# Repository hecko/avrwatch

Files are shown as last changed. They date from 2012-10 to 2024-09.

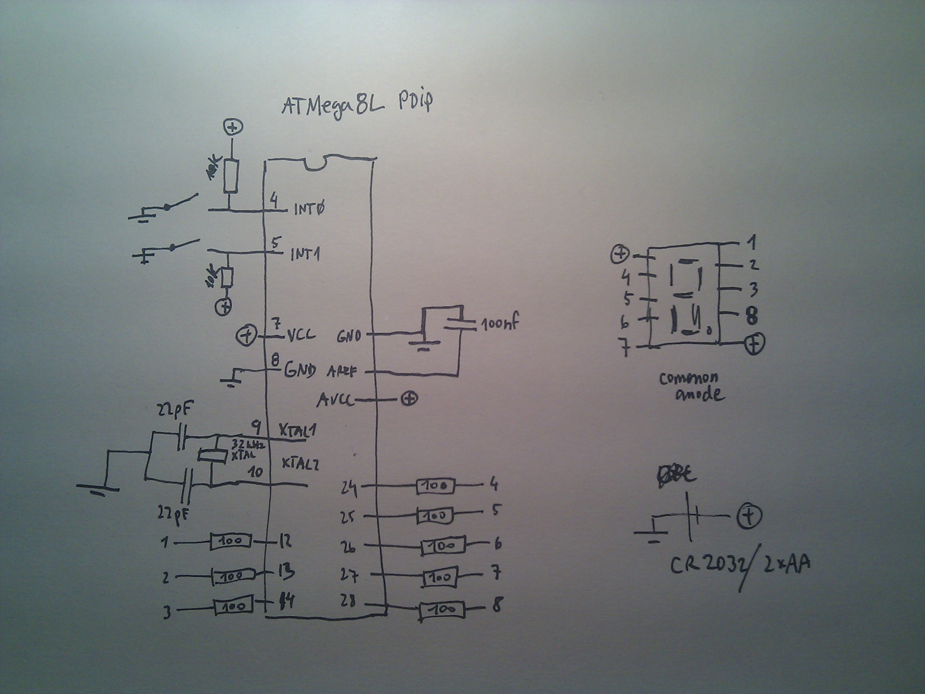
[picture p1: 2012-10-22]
doc/wiring.jpg

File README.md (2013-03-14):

plne funkcna a otestovana na ATMega8L - PDIP verzia

  xtal (32kHz) musi byt zapojeny s externymi kondenzatormi (pozri errata v datasheete atmega8l) - pouzite 22pF (oznacenie 22) (na kazdej nozicke prepojene s GND)
  vsetky GND prepojene
  vsetky VCC prepojene
  AREF prepojeny cez 100n (oznacenie 104) kondenzator na GND
  7 segment display SA36-11GWA cez cca 100 Ohm odpory (spolocna anoda)
  tlacitla su medi INT pinmi a GND s 10K resistormi na pinoch do VCC
  napajane cez CR2032, alebo 2xAA 

wiring

programovanie je testovane na programatore usbtiny

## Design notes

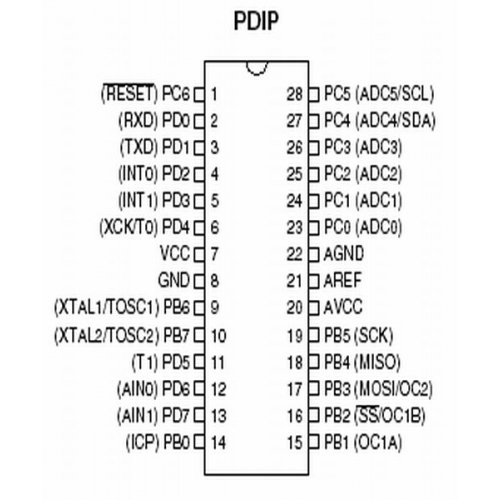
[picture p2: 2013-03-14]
doc/atmega8.jpg

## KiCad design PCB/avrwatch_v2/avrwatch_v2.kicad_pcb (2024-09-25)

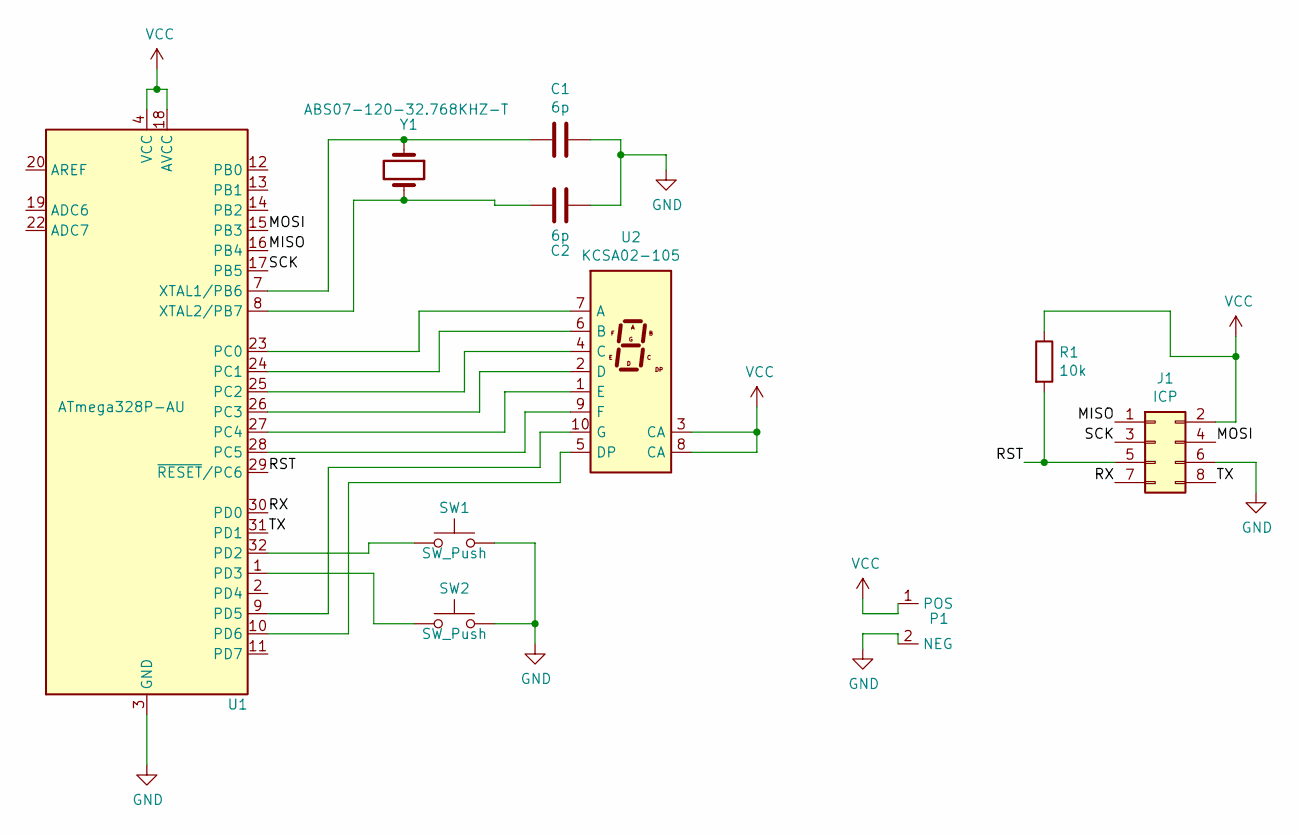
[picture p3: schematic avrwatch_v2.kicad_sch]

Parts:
C1, C2: 6p; C_0603_1608Metric
J1: ICP; PinHeader_2x04_P2.54mm_Vertical
P1: CR2032-120591
R1: 10k; R_0603_1608Metric
SW1, SW2: SW_Push; SW_PUSH_6mm_H9.5mm_center
U1: ATmega328P-AU; TQFP-32_7x7mm_P0.8mm
U2: KCSA02-105; KCSC02-105
Y1: ABS07-120-32.768KHZ-T; Crystal_SMD_3215-2Pin_3.2x1.5mm; FARNELL 2467864

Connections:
/MISO: J1.1, U1.16 (PB4)
/MOSI: J1.4, U1.15 (PB3)
/RST: J1.5, R1.2, U1.29 (~RESET/PC6)
/RX: J1.7, U1.30 (PD0)
/SCK: J1.3, U1.17 (PB5)
/TX: J1.8, U1.31 (PD1)
GND: C1.1, C2.1, J1.6, P1.2 (NEG), SW1.2, SW2.2, U1.3 (GND), U1.5 (GND), U1.21 (GND)
unnamed: U1.23 (PC0), U2.7 (A)
unnamed: U1.24 (PC1), U2.6 (B)
unnamed: U1.25 (PC2), U2.4 (C)
unnamed: U1.26 (PC3), U2.2 (D)
unnamed: U1.27 (PC4), U2.1 (E)
unnamed: U1.28 (PC5), U2.9 (F)
unnamed: SW1.1, U1.32 (PD2)
unnamed: SW2.1, U1.1 (PD3)
unnamed: U1.9 (PD5), U2.10 (G)
unnamed: U1.10 (PD6), U2.5 (DP)
unnamed: C1.2, U1.7 (XTAL1/PB6), Y1.1
unnamed: C2.2, U1.8 (XTAL2/PB7), Y1.2
VCC: J1.2, P1.1 (POS), R1.1, U1.4 (VCC), U1.6 (VCC), U1.18 (AVCC), U2.3 (CA), U2.8 (CA)

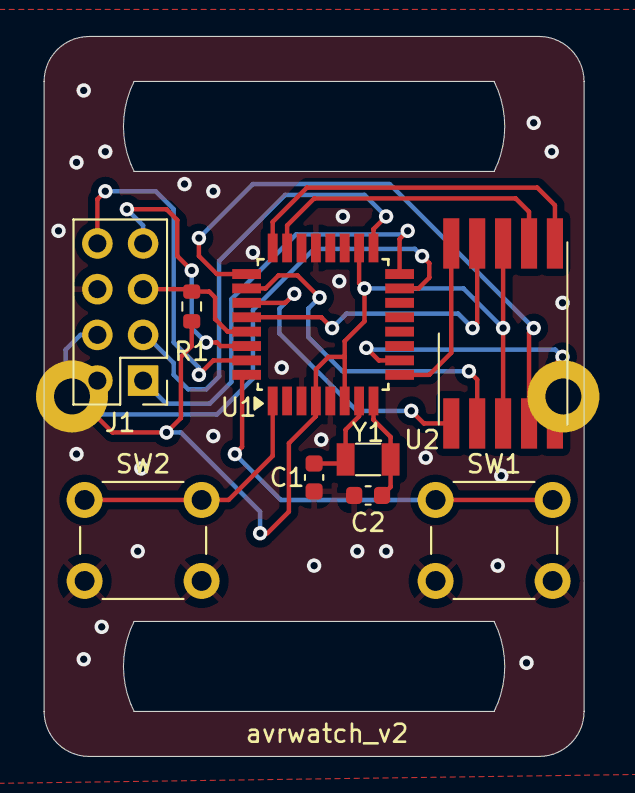
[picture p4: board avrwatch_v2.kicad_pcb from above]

Board: 2 copper layers, 30.0 x 40.0 mm, 10 parts (1 on the bottom side), 20 nets.

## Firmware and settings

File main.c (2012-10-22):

// segment.c
// Unix-watch Hodinky ukazujuce okrem datumu a casu
// aj unix epochu
// verzia ATMEGA8/48/88/168/328
// RTC - Interny
// Display - 7+1 segmentovy led display
// Autor: Marek Blasko, Marcel Hecko 

// standadne kniznice
#include <avr/interrupt.h>
#include <avr/pgmspace.h>
#include <util/delay.h>

#include "rtc.h"	// rtc utility
#include "segment.h"	//7-segment library

// globalne premenne
volatile unsigned char sec1 = 0;
volatile unsigned char sec10 = 0;
volatile unsigned char min1 = 0;
volatile unsigned char min10 = 0;
volatile unsigned char hod = 0;
volatile unsigned char show = 1;
volatile unsigned char setup = 1;
volatile unsigned char show_setup = 1;
volatile unsigned char setup_hod = 1;
volatile unsigned char setup_min = 1;

void increment_time(void) {
  sec1++;
  if(sec1>9){
    sec1=0;
    sec10++;
  } 
  if(sec10>5){
    sec10=0;
    min1++; 
  }
  if(min1>9){
    min1=0;
    min10++; 
  }
  if(min10>5){
    min10=0;
    hod++; 
  }
  if(hod>11){
    hod=0;
  }
}

// rutina na zachytavanie RTC preruseni
ISR(TIMER2_OVF_vect) {
  increment_time();
}

//pin D2
ISR(INT0_vect) {
  segments(13);
  //ked podrzime gombicek dlhsie prejdeme, alebo odideme z/do setup modu
  volatile unsigned char val;
  volatile unsigned int i = 0;
  val = PIND & 0x04; //nacitanie hodnoty tlacitka na D2
  while (val==0x00) {
    val = PIND & 0x04; 
    i++; //pocitaj ako dlho mame stlacene tlacitko D2
    _delay_ms(10);
    if (i>=100) {
      segments(14);
    }
  }

  if (i>=100) { //ak bolo tlacitko stlacene dlho
    if (setup==1) { //ak nie sme v setupe tak startujeme setup mode
      setup=0;
      setup_hod=0;
    } else { //ak sme uz v setupe, tak sa z neho exitneme
      setup=1;
      setup_hod=1;
      setup_min=1;
    }
    segments_off();
  } else {
    if (setup==0 && setup_hod==0) { // ak sme drzali tlacitko kratko tak sa prepneme na nastavovanie daneho parametru 
      setup_hod=1;
      setup_min=0;
    } else {  //ak nie sme v setupe po kratkom stlaceni tlacitka zobraz nic 

    }
  }

}

//pin D3
ISR(INT1_vect) {
  if (setup==0 && setup_min==0) {
    _delay_ms(200);
    min1++;  //zvys cas o jednu minutu
    increment_time();
    sec1 = 0;
    sec10 = 0;
  } else if (setup==0 && setup_hod==0) {
    _delay_ms(200);
    hod++;  //zvys cas o jednu minutu
    increment_time();
  } else {
    show=0;
  }
}

int main(void) {
  //zapneme pocitanie casu
  rtc_init();

  //katodova LED - low je zapnuty
  //nastavenie pinov LED portov ako output (1)
  DDRB |= 0x3F;
  DDRD |= 0xC0;

  //nastavenie D3 a D4 pinov ako input (buttons) (0)
  DDRD &= ~0x18;
  GICR |= (1<<INT0);
  GICR |= (1<<INT1);

  //zacina zapnute (kontrola)
  _delay_ms(2000);
  segments_off();

  sei();

  while(1){
    // ked nie sme v setup rezime a mame nastavene show
    if (show==0) {
      //ukazujem aktualny cas
      segments(hod);
      _delay_ms(250);
      segments_off();
      _delay_ms(100);
      segments(min10);
      _delay_ms(150);
      segments_off();
      _delay_ms(50);
      segments(min1);
      _delay_ms(150);
      segments_off();
      show=1;
    }
    if (setup==0 && setup_hod==0) {
      //we are in setup mode for hours
      segments(hod);
      _delay_ms(150);
      segments_off();
      _delay_ms(250);
    } else if (setup==0 && setup_min==0) {
      //show minutes (tens)
      segments(min10);
      _delay_ms(100);
      segments_off();
      _delay_ms(30);
      //show minutes (ones)
      segments(min1);
      _delay_ms(100);
      segments_off();
      _delay_ms(300);
    }
  } 
}

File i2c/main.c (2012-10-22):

// standadne kniznice
#include <stdlib.h>
#include <avr/interrupt.h>
#include <avr/pgmspace.h>

#include "rtc.h"	// rtc utility
#include "segment.c"	//7-segment library

#include "i2cmaster.h"
#define ds1307 0xD0

#define TRUE 1
#define FALSE 0

// globalne premenne
volatile unsigned char now[5]; // sekundy, desiatky sekund, minuty, desiatky minut, hodiny 
volatile unsigned char chng;
volatile unsigned char show;

// rutina na zachytaanie RTC preruseni
/*ISR(TIMER2_OVF_vect)
{
   now[0]++;   //inkrementjeme unix epochu sekundy
   if (now[0]>9)
      {
      now[0]=0;
      now[1]++;
      if (now[1]>5) {
        now[1]=0;
        now[2]++;
        if (now[2]>9) {
          now[2]=0;
          now[3]++; //desiatky minut
          if(now[3]>5) {
            now[3]=0;
            now[4]++; //hodiny
            if(now[4]>11) {
              now[4]=0;
            }
          }
        }
      }
    }
  chng=0;
}
*/

ISR_ALIAS(INT1_vect, INT0_vect);

ISR(INT0_vect) {
  _delay_ms(20);
  show=0;
}

uint8_t ret;

uint8_t ds1307_write(uint8_t address,uint8_t data) {
  i2c_start_wait(ds1307+I2C_WRITE);
  i2c_write(address);
  i2c_write(data); 
  i2c_stop();
  return TRUE;
}


uint8_t ds1307_read(uint8_t address,uint8_t *data) {
  i2c_start_wait(ds1307+I2C_WRITE);
  i2c_write(address); 
  i2c_start_wait(ds1307+I2C_READ);
  *data = i2c_readNak();
  i2c_stop();
  return TRUE;
}

void ds1307_init() {
  uint8_t temp; 

  ds1307_read(0x00,&temp);
  temp&=(~(1<<7));  	//Clear CH Bit - spusti casovac
  ds1307_write(0x00,temp);
}

int main(void) {

  uint8_t cas;

  i2c_init();
  ds1307_init();

  _delay_ms(2000);
  //zapneme pocitanie casu
  rtc_init();

  //katodova LED - low je zapnuty
  //nastavenie pinov ako output
  DDRB = 0xff;
  DDRD = 0xff;

  //nastavenie D3 a D4 pinov ako input (buttons)
  DDRD |= 0b00011000;
  GICR |= (1<<INT0);
  GICR |= (1<<INT1);

  //zacina zapnute (kontrola)
  PORTB = 0x00;
  PORTD &= ~0b11000000;
  _delay_ms(2000);
  segments_off();

  i2c_init();
  ds1307_init();

  //sei();

  while(1){
//    if (show==0) {
      ds1307_read(0x00,&cas);
      //PORTB = cas;
      segments(cas);
      //_delay_ms(350);
      PORTB &= ~PORTB; //clear na nuly
      PORTB = ~PORTB; // nastavit jednicky na zhasnutie
      _delay_ms(150);
//      show=1;
/*
      for(int i=4;i>=0;i--) {
        segments(now[i]);
        segments_off();
        _delay_ms(50);
        show=1;
      }
*/
//    }
  }
}

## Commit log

2012-10-22 added wiring diagram
2021-12-16 simplest possible design with atmega328p
    [avrwatch_v2.kicad_pcb, avrwatch_v2.sch]
2024-09-25 finishing the pcb
    [avrwatch_v2.kicad_pcb, avrwatch_v2.kicad_sch, avrwatch_v2.sch]
2024-09-25 needs battery fixing
    [avrwatch_v2.kicad_pcb, avrwatch_v2.kicad_sch]
